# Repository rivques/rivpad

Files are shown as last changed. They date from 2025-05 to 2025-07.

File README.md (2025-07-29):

# rivpad
a [hackpad](https://hackpad.hackclub.com) macropad. designed to be a system monitor so i can tell if the program that's hanging in my terminal is actually doing something or not

## features
- 9 keys
- OLED display
- 16 RGB LEDs, intended as system monitors
- PCB-mount style, no top plate
- optional USB port for daisy chaining keyboards

## demo link
[demo](https://youtube.com/shorts/DjA1d4YHZ9s?feature=share)

## cad
The CAD is in an Onshape document available [here](https://cad.onshape.com/documents/859a6718b395782d916274d9/w/acb2d55d003e03c3719d4ca6/e/6f143904c3132775702816f5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).

## a note on the custom firmware
because i want to use the RGB LEDs to monitor system load, i had to write custom firmware, because neither qmk nor kmk supports getting info from the host like that.

## a note on the usb port
the USB port is optional. it's intended to forward HID packets from a second keyboard using pico-pio-usb. because this would require even more custom firmware, i don't plan to do it immediately but did break out the required pins on the PCB.

## screenshots
### overall

### case

### schematic

### pcb


| Quantity | Item | Source | Optional |
|---|---|---|---|
| 1 | XIAO RP2040 | [hackpad kit](https://hackpad.hackclub.com/parts) | No |
| 16 | SK6812MINI-E RGB LEDs | [hackpad kit](https://hackpad.hackclub.com/parts) | No |
| 9 | Cherry MX-style switches | [hackpad kit](https://hackpad.hackclub.com/parts) | No |
| 9 | 1N4148 diodes | [hackpad kit](https://hackpad.hackclub.com/parts) | No |
| 1 | 0.91" OLED display | [hackpad kit](https://hackpad.hackclub.com/parts) | No |
| 2 | 4.7kΩ resistors | [hackpad kit](https://hackpad.hackclub.com/parts) | No |
| 9 | DSA keycaps | [hackpad kit](https://hackpad.hackclub.com/parts) | No |
| 1 | 3D-printed case | [hackpad kit](https://hackpad.hackclub.com/parts) | No |
| 1 | PCB | [jlcpcb.com](https://jlcpcb.com) | No |
| 4 | M3x10mm bolts | [hackpad kit](https://hackpad.hackclub.com/parts) | No |
| 4 | M3 heat-set inserts | [hackpad kit](https://hackpad.hackclub.com/parts) | No |
| 4 | Anti-slip rubber feet | [these](https://www.adafruit.com/product/550) | Yes |
| 1 | USB-A female connector | [this](https://www.digikey.com/en/products/detail/on-shore-technology-inc/USB-A1HSW6/2677750) | Yes |

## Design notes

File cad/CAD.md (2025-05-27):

You can see the full CAD on [Onshape](https://cad.onshape.com/documents/859a6718b395782d916274d9/w/acb2d55d003e03c3719d4ca6/e/6f143904c3132775702816f5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).

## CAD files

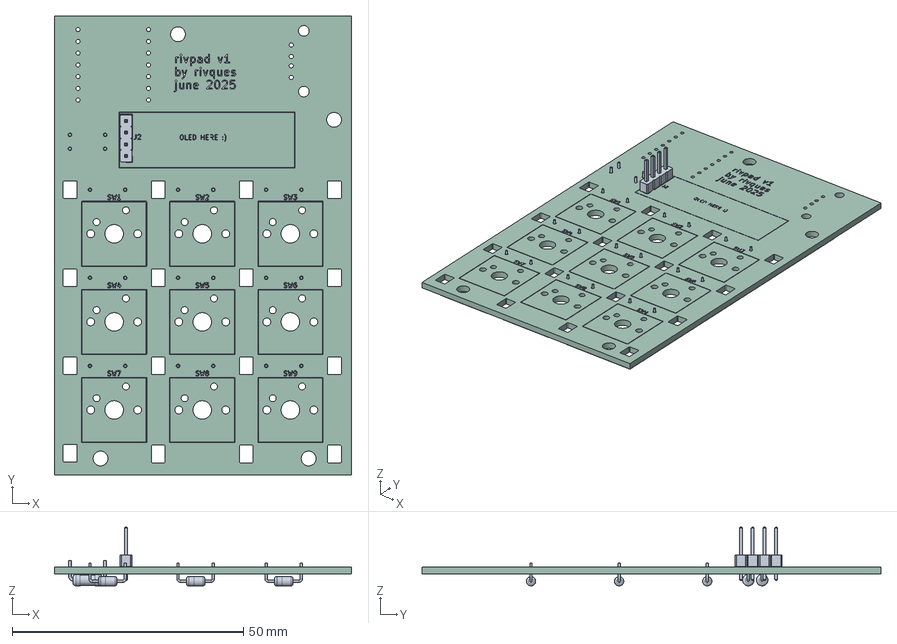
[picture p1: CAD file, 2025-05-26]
pcb/rivpad-pcb.step
64.2 x 99.3 x 12.7 mm
PinHeader_1x04_P2.54mm_Vertical
D_DO-35_SOD27_P7.62mm_Horizontal x 9
R_Axial_DIN0207_L6.3mm_D2.5mm_P7.62mm_Horizontal x 2
rivpad_silkscreen
rivpad_PCB

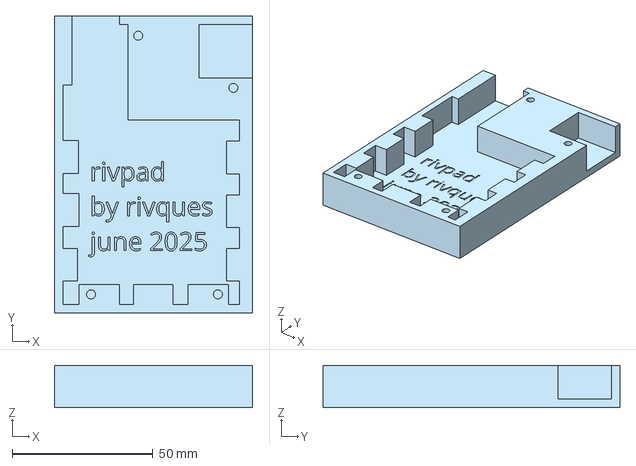
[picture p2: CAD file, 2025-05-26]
production/case.step
70.2 x 105.3 x 15.0 mm

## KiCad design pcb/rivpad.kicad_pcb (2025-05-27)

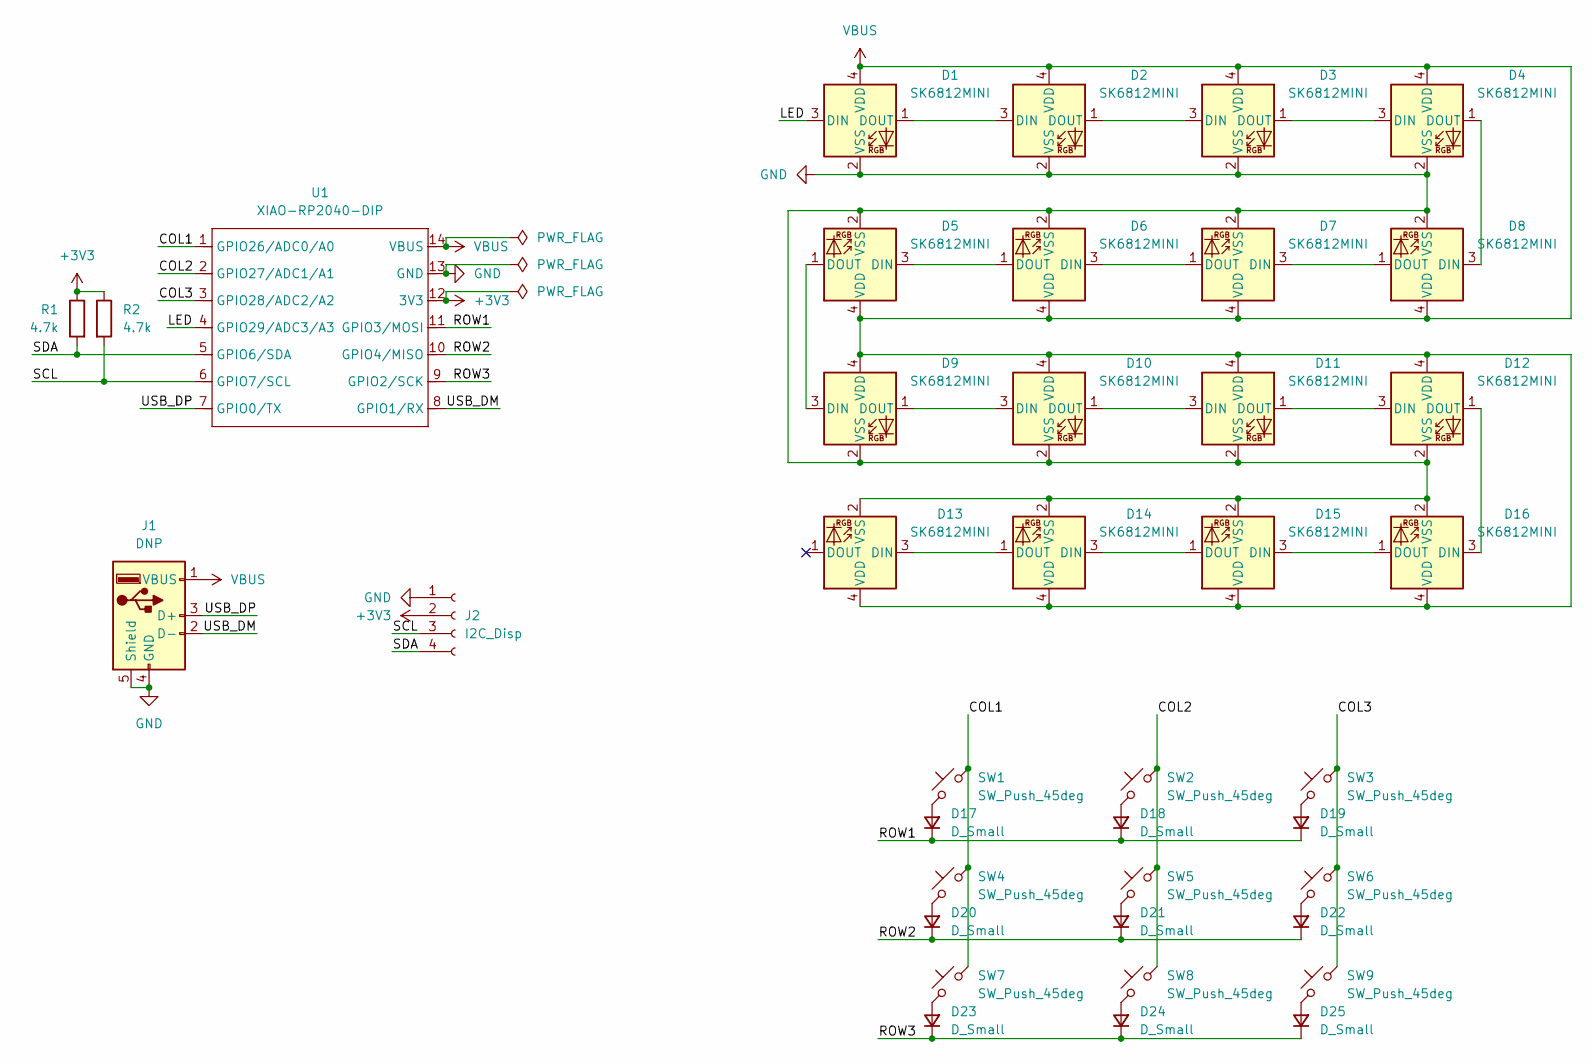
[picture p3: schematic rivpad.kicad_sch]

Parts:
D1, D2, D3, D4, D5, D6, D7, D8, D9, D10, D11, D12, D13, D14, D15, D16: SK6812MINI; SK6812-MINI-E
D17, D18, D19, D20, D21, D22, D23, D24, D25: D_Small; D_DO-35_SOD27_P7.62mm_Horizontal
J1: DNP; USB_A_Connfly_DS1095
J2: I2C_Disp; PinHeader_1x04_P2.54mm_Vertical
R1, R2: 4.7k; R_Axial_DIN0207_L6.3mm_D2.5mm_P7.62mm_Horizontal
SW1, SW2, SW3, SW4, SW5, SW6, SW7, SW8, SW9: SW_Push_45deg; SW_Cherry_MX_1.00u_PCB
U1: XIAO-RP2040-DIP

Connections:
+3V3: J2.2, R1.1, R2.1, U1.12 (3V3)
/COL1: SW1.2, SW4.2, SW7.2, U1.1 (GPIO26/ADC0/A0)
/COL2: SW2.2, SW5.2, SW8.2, U1.2 (GPIO27/ADC1/A1)
/COL3: SW3.2, SW6.2, SW9.2, U1.3 (GPIO28/ADC2/A2)
/LED: D1.3 (DIN), U1.4 (GPIO29/ADC3/A3)
/ROW1: D17.1 (K), D18.1 (K), D19.1 (K), U1.11 (GPIO3/MOSI)
/ROW2: D20.1 (K), D21.1 (K), D22.1 (K), U1.10 (GPIO4/MISO)
/ROW3: D23.1 (K), D24.1 (K), D25.1 (K), U1.9 (GPIO2/SCK)
/SCL: J2.3, R2.2, U1.6 (GPIO7/SCL)
/SDA: J2.4, R1.2, U1.5 (GPIO6/SDA)
/USB_DM: J1.2 (D-), U1.8 (GPIO1/RX)
/USB_DP: J1.3 (D+), U1.7 (GPIO0/TX)
GND: D1.2 (VSS), D2.2 (VSS), D3.2 (VSS), D4.2 (VSS), D5.2 (VSS), D6.2 (VSS), D7.2 (VSS), D8.2 (VSS), D9.2 (VSS), D10.2 (VSS), D11.2 (VSS), D12.2 (VSS), D13.2 (VSS), D14.2 (VSS), D15.2 (VSS), D16.2 (VSS), J1.4 (GND), J1.5 (Shield), J2.1, U1.13 (GND)
unnamed: D1.1 (DOUT), D2.3 (DIN)
unnamed: D2.1 (DOUT), D3.3 (DIN)
unnamed: D3.1 (DOUT), D4.3 (DIN)
unnamed: D4.1 (DOUT), D8.3 (DIN)
unnamed: D5.3 (DIN), D6.1 (DOUT)
unnamed: D5.1 (DOUT), D9.3 (DIN)
unnamed: D6.3 (DIN), D7.1 (DOUT)
unnamed: D7.3 (DIN), D8.1 (DOUT)
unnamed: D9.1 (DOUT), D10.3 (DIN)
unnamed: D10.1 (DOUT), D11.3 (DIN)
unnamed: D11.1 (DOUT), D12.3 (DIN)
unnamed: D12.1 (DOUT), D16.3 (DIN)
unnamed: D13.3 (DIN), D14.1 (DOUT)
unnamed: D14.3 (DIN), D15.1 (DOUT)
unnamed: D15.3 (DIN), D16.1 (DOUT)
unnamed: D17.2 (A), SW1.1
unnamed: D18.2 (A), SW2.1
unnamed: D19.2 (A), SW3.1
unnamed: D20.2 (A), SW4.1
unnamed: D21.2 (A), SW5.1
unnamed: D22.2 (A), SW6.1
unnamed: D23.2 (A), SW7.1
unnamed: D24.2 (A), SW8.1
unnamed: D25.2 (A), SW9.1
VBUS: D1.4 (VDD), D2.4 (VDD), D3.4 (VDD), D4.4 (VDD), D5.4 (VDD), D6.4 (VDD), D7.4 (VDD), D8.4 (VDD), D9.4 (VDD), D10.4 (VDD), D11.4 (VDD), D12.4 (VDD), D13.4 (VDD), D14.4 (VDD), D15.4 (VDD), D16.4 (VDD), J1.1 (VBUS), U1.14 (VBUS)

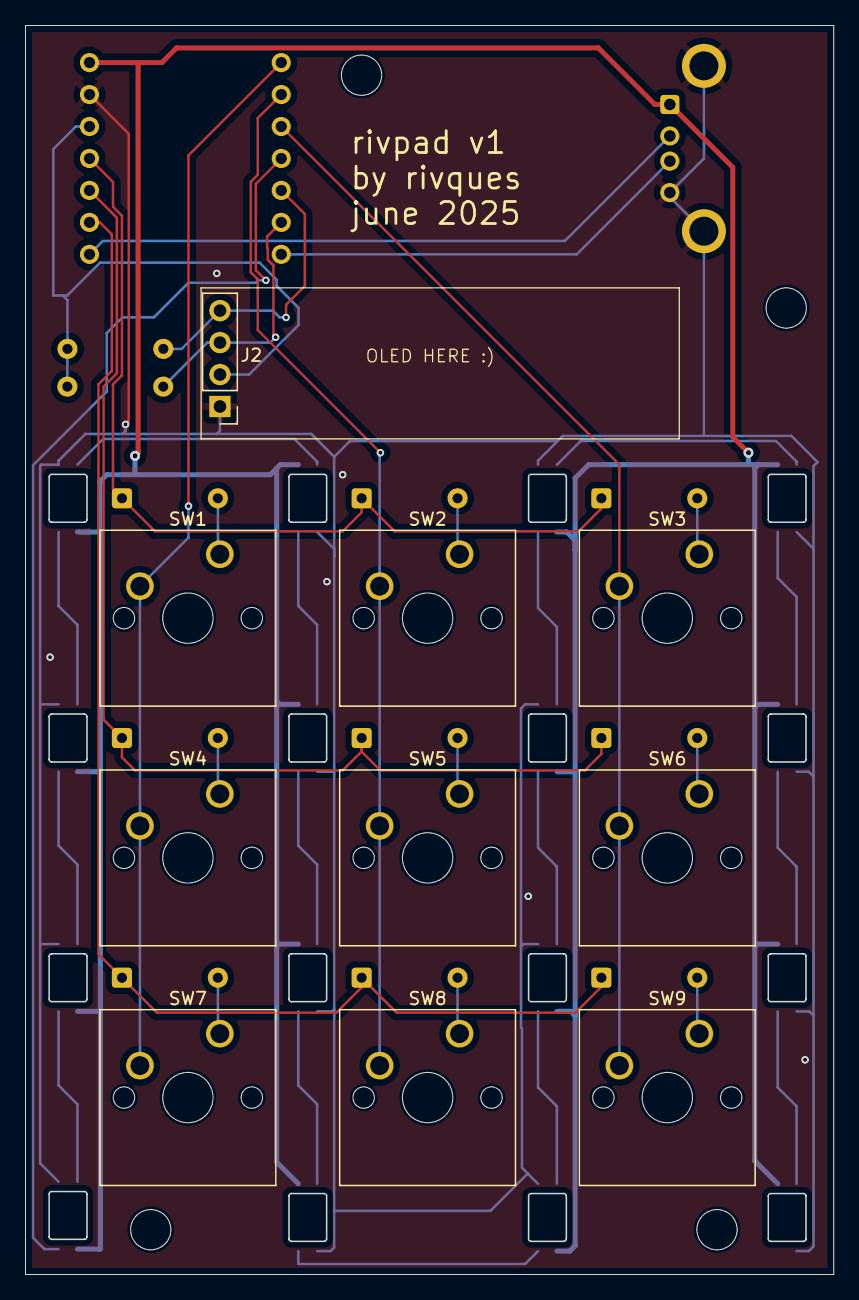
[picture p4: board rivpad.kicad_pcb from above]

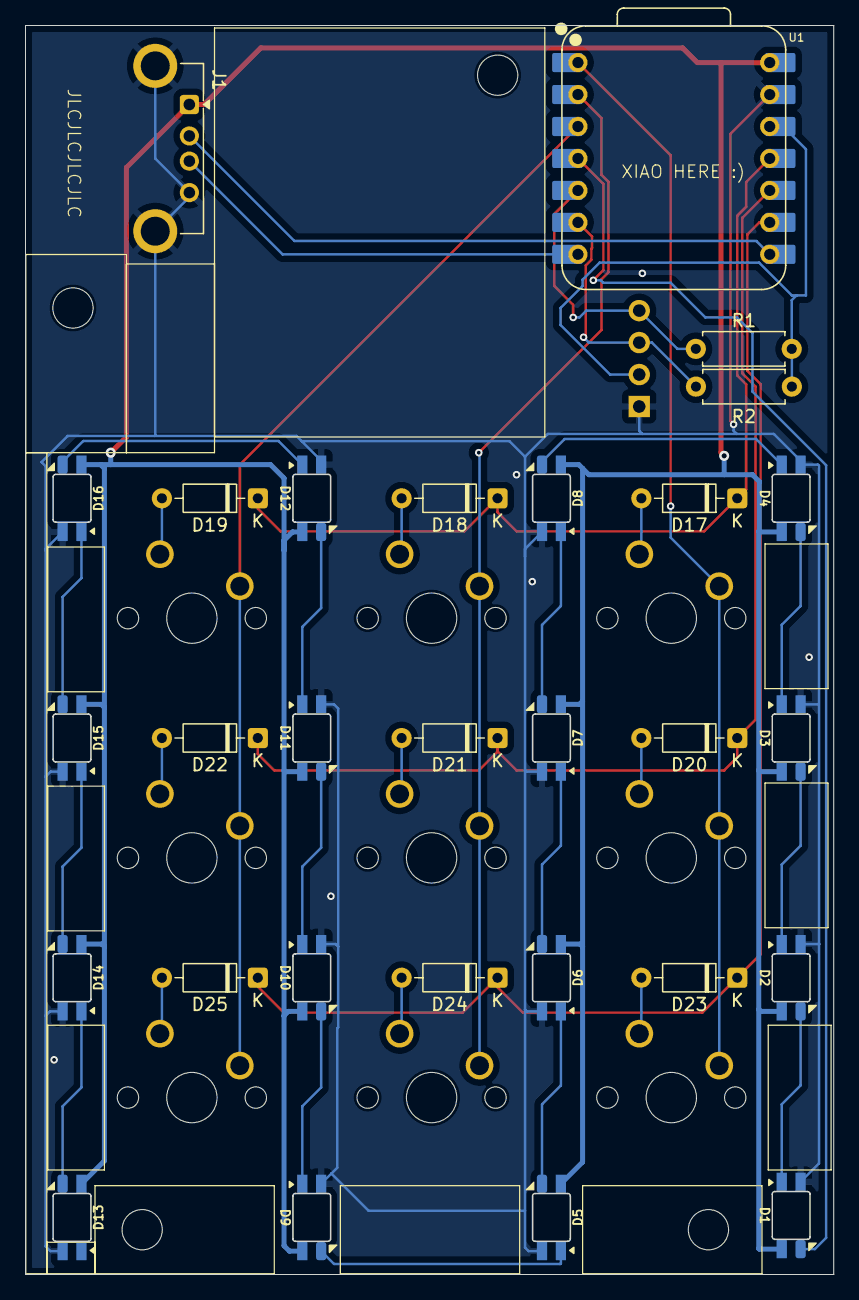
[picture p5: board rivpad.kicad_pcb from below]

Board: 2 copper layers, 64.2 x 99.3 mm, 39 parts (29 on the bottom side), 38 nets.

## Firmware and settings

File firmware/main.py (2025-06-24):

# Custom firmware for the rivpad macropad.
# In addition to sending keycodes, it also uses neopixels and an OLED to show system resource utilization.

import board
import neopixel
import displayio
import usb_cdc
import adafruit_displayio_ssd1306
import i2cdisplaybus
from lib.adafruit_display_text.label import Label
import terminalio
import usb_hid
from lib.adafruit_hid.keyboard import Keyboard
from lib.adafruit_hid.keycode import Keycode
import keypad

keyboard = Keyboard(usb_hid.devices)

matrix = keypad.KeyMatrix(row_pins=[board.D10, board.D9, board.D8], column_pins=[board.D0, board.D1, board.D2])

pixels = neopixel.NeoPixel(board.D3, 16, brightness=0.1, auto_write=False)
pixel_map = [15, 14, 13, 12, 8, 9, 10, 11, 7, 6, 5, 4, 0, 1, 2, 3]

displayio.release_displays()  # Release any existing displays
oled_bus = i2cdisplaybus.I2CDisplayBus(board.I2C(), device_address=0x3C)
oled = adafruit_displayio_ssd1306.SSD1306(oled_bus, width=128, height=32)
group = displayio.Group()
oled.root_group = group
label = Label(terminalio.FONT, text="    Rivpad Macropad   ", color=0xFFFFFF, x=0, y=12, scale=1)
group.append(label)

# keycodes from https://github.com/jtroo/kanata/blob/main/parser/src/keys/mod.rs
base_kbd_layer = [
    "layer", # the layer change key
    Keycode.KEYPAD_ONE, # mute microphone (handled by cinnamon shortcut)
    Keycode.KEYPAD_TWO, # toggle audio output device (handled by kanata)
    Keycode.KEYPAD_THREE, # open terminal (handled by cinnamon shortcut)
    Keycode.KEYPAD_FOUR, # open file manager (handled by cinnamon shortcut)
    Keycode.KEYPAD_FIVE, # open browser (handled by cinnamon shortcut)
    (Keycode.SHIFT, Keycode.GUI), # super+shift to push windows, handled by cinnamon natively
    Keycode.KEYPAD_SEVEN, # toggle maximize window (handled by cinnamon shortcut)
    Keycode.KEYPAD_EIGHT, # take screenshot to clipboard (handled by cinnamon shortcut)
]

power_kbd_layer = [
    "layer", # the layer change key
    None, 
    Keycode.KEYPAD_ZERO, # sleep (handled by cinnamon shortcut)
    None,
    None,
    None,
    None,
    None,
    Keycode.POWER, # open power menu (handled by cinnamon natively)
]

power_layer_active = False

if usb_cdc.data is None:
    raise RuntimeError("USB CDC data port not available. Ensure boot.py is on the board and ran successfully.")
usb_cdc.data.timeout = 0.1  # Set a timeout for reading data

system_resources = [
    {
        "name": "CPUav",
        "hue": 0,  # Red
    },
    {
        "name": "CPUpk",
        "hue": 50,  # Orange
    },
    {
        "name": "RAM",
        "hue": 100,  # Yellow
    },
    {
        "name": "Disk",
        "hue": 200,  # Cyan
    },
    {
        "name": "Net",
        "hue": 150,  # Green
    },
    {
        "name": "GPU",
        "hue": 300,  # Magenta
    },
    {
        "name": "VRAM",
        "hue": 250,  # Blue
    },
]

def hsv_to_rgb_raw(hue, saturation=1.0, value=1.0):
    """Convert HSV to RGB color space."""
    hue = float(hue) / 360.0  # Normalize hue to [0, 1)
    if saturation == 0.0:
        return (value, value, value)
    i = int(hue * 6.0)  # hue is in [0, 1), multiply by 6
    f = (hue * 6.0) - i
    p = value * (1.0 - saturation)
    q = value * (1.0 - f * saturation)
    t = value * (1.0 - (1.0 - f) * saturation)
    i %= 6
    if i == 0:
        return (value, t, p)
    elif i == 1:
        return (q, value, p)
    elif i == 2:
        return (p, value, t)
    elif i == 3:
        return (p, q, value)
    elif i == 4:
        return (t, p, value)
    elif i == 5:
        return (value, p, q)
    else:
        # unreachable
        return (0, 0, 0)

def hsv_to_rgb(hue, saturation=1.0, value=1.0):
    """Convert HSV to RGB color space and scale to 0-255 range."""
    r, g, b = hsv_to_rgb_raw(hue, saturation, value)
    return (int(r * 255), int(g * 255), int(b * 255))

while True:
    # Check for key presses
    event = matrix.events.get()
    if event:
        key_number = event.key_number
        key = base_kbd_layer[key_number] if not power_layer_active else power_kbd_layer[key_number]
        print(f"Key {key_number} {'pressed' if event.pressed else 'released'} on {'base' if not power_layer_active else 'power'}: {key}")  # Debug output
        if event.pressed:
            if key == "layer":
                power_layer_active = True
                keyboard.release_all()
            elif isinstance(key, tuple):
                keyboard.press(*key)
            elif key is not None:
                keyboard.press(key)
        else:
            if key == "layer":
                power_layer_active = False
                keyboard.release_all()
            elif isinstance(key, tuple):
                keyboard.release(*key)
            elif key is not None:
                keyboard.release(key)
    
    # get system resource utilization from the serial port, if available
    if usb_cdc.data.in_waiting > 0:
        data_raw = usb_cdc.data.readline(32)
        data = data_raw.decode('utf-8').strip().split(',')
        # a daemon running on the host is expected to send a comma-separated list of utilization percents
        # like "30,90,48,3,5,15,30\n" for CPUav, CPUpk, RAM, Disk, Net, GPU, VRAM
        resource_values = [int(x) for x in data if x.isdigit()]
        if len(data) != len(system_resources):
            # there was an error in the data, skip this iteration
            print(f"Error: Expected {len(system_resources)} values, got {len(data)}. Data: {data}")
            continue

        # pick the biggest 4 values and grab their corresponding names/hues
        cpu_av_index = 0
        cpu_pk_index = 1
        top_resources = sorted(zip(resource_values, system_resources), reverse=True, key=lambda x: x[0])[:5]
        # trim the list to 4, either by eliminating the lower of CPUav or CPUpk, or by removing the lowest value if both aren't present
        cpu_av_present = any(resource["name"] == "CPUav" for _, resource in top_resources)
        cpu_pk_present = any(resource["name"] == "CPUpk" for _, resource in top_resources)
        if cpu_av_present and cpu_pk_present:
            # both are present, keep the one with the higher value
            if resource_values[cpu_av_index] > resource_values[cpu_pk_index] - 20:
                top_resources = [r for r in top_resources if r[1]["name"] != "CPUpk"]
            else:
                top_resources = [r for r in top_resources if r[1]["name"] != "CPUav"]
        else:
            # neither is present, just keep the top 4
            top_resources = top_resources[:4]

        # update the neopixels
        for i, (value, resource) in enumerate(top_resources):
            hue = resource["hue"]
            rgb_full = hsv_to_rgb(hue, saturation=1.0, value=1.0)
            rgb_last = hsv_to_rgb(hue, saturation=1.0, value=(value / 25.0) % 1.0)
            num_full_pixels = int(value / 25.0)
            pixel_values = []
            for j in range(4):
                if j < num_full_pixels:
                    pixel_values.append(rgb_full)
                elif j == num_full_pixels:
                    pixel_values.append(rgb_last)
                else:
                    pixel_values.append((0, 0, 0))
            print(f"Resource {resource['name']}: {value}% - RGB: {pixel_values} at index {i}")  # Debug output
            for pix_idx in range(i * 4, i * 4 + 4):
                if pix_idx > 15:
                    print(f"Warning: pix_idx {pix_idx} is out of range for pixel_map (len {len(pixel_map)})")
                    print(f"i: {i}, num_full_pixels: {num_full_pixels}, value: {value}, resource: {resource}")
                    print(f"data: {data}, resource_values: {resource_values}")
                    continue
                try:
                    pixels[pixel_map[pix_idx]] = pixel_values[pix_idx % 4]
                except IndexError:
                    print(f"IndexError: Either pix_idx {pix_idx} is out of range for pixel_map (len {len(pixel_map)}),")
                    print(f"there aren't enough pixel_values (len {len(pixel_values)}) for the pixel at index {pix_idx},")
                    print(f"or the mapped value {pixel_map[pix_idx]} is out of range for pixels (len 16)")
        pixels.show()

        # update the OLED display
        label_text = "|".join(f"{resource['name']}" for _, resource in top_resources)
        label_text += "\n" + "|".join(f"{value:^{len(resource['name'])-1}}%" for value, resource in top_resources)
        label.text = label_text

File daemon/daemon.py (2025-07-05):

import time
import psutil
import serial
import serial.tools.list_ports
from pynvml import nvmlInit, nvmlDeviceGetHandleByIndex, nvmlDeviceGetUtilizationRates, nvmlDeviceGetMemoryInfo
import threading

# Initialize NVIDIA Management Library
nvmlInit()
gpu_handle = nvmlDeviceGetHandleByIndex(0)  # Assuming a single GPU

# Automatically detect the serial port with VID 0x1209 and PID 0x0001
ports = serial.tools.list_ports.comports()
selected_port = None
for port in ports:
    if port.vid == 0x1209 and port.pid == 0x0001:
        if selected_port is None or int(port.device[-1]) > int(selected_port[-1]):
            selected_port = port.device

print(f"Using serial port: {selected_port}")  # Log the selected serial port

# Initialize serial communication
serial_port = serial.Serial(selected_port, baudrate=9600, timeout=1)

def get_system_utilization():
    """Gather system utilization metrics."""
    # CPU average utilization
    cpu_av = psutil.cpu_percent(interval=1)

    # CPU peak utilization
    cpu_pk = max(psutil.cpu_percent(percpu=True))

    # RAM utilization
    ram = psutil.virtual_memory().percent

    # Disk utilization
    disk = psutil.disk_usage('/').percent

    # Network utilization (approximation based on bytes sent/received)
    net_io_start = psutil.net_io_counters()
    time.sleep(1)  # Measure over 1 second
    net_io_end = psutil.net_io_counters()
    net = ((net_io_end.bytes_sent + net_io_end.bytes_recv) - (net_io_start.bytes_sent + net_io_start.bytes_recv)) / (1024 * 1024)  # MB/s

    # GPU utilization
    gpu_util = nvmlDeviceGetUtilizationRates(gpu_handle).gpu

    # VRAM utilization
    vram_info = nvmlDeviceGetMemoryInfo(gpu_handle)
    vram = (vram_info.used / vram_info.total) * 100

    return [
        int(cpu_av),
        int(cpu_pk),
        int(ram),
        int(disk),
        int(net),
        int(gpu_util),
        int(vram)
    ]


def main():
    global serial_port
    while True:
        try:
            # Check if the serial port is open
            if not serial_port.is_open:
                print("Serial port disconnected. Attempting to reconnect...")
                serial_port.close()  # Ensure it's closed before reconnecting
                ports = serial.tools.list_ports.comports()
                selected_port = None
                for port in ports:
                    if port.vid == 0x1209 and port.pid == 0x0001:
                        selected_port = port.device
                        

                if selected_port:
                    serial_port = serial.Serial(selected_port, baudrate=9600, timeout=1)
                    print(f"Reconnected to serial port: {selected_port}")
                else:
                    print("No valid serial port found. Retrying in 5 seconds...")
                    time.sleep(5)
                    continue

            # Get utilization metrics
            utilization = get_system_utilization()

            # Format as comma-separated string
            utilization_str = ','.join(map(str, utilization)) + '\n'

            # Send over serial
            buf = utilization_str.encode('utf-8')
            bytes_sent = serial_port.write(buf)

            # Debug output
            print(f"Sent ({bytes_sent}): {utilization_str.strip()}")

            time.sleep(1)  # Add a delay to reduce CPU usage

        except serial.SerialException as e:
            print(f"Serial error: {e}. Attempting to reconnect...")
            serial_port.close()
            time.sleep(5)  # Wait before retrying

        except Exception as e:
            print(f"Error: {e}")
            time.sleep(1)  # Add a delay to avoid rapid error loops

if __name__ == "__main__":
    main()

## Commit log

2025-05-26 make pcb!
    [rivpad.kicad_pcb, rivpad.kicad_sch]
2025-05-26 add mounting holes to board and adjust readme
    [rivpad-pcb.step, rivpad.kicad_pcb]
2025-05-26 add case cad
    [case.step]
2025-05-27 get things in the right shape for submission
    [case.step, rivpad.kicad_pcb]
2025-06-24 fix a few bugs in the firmware
    [main.py]
